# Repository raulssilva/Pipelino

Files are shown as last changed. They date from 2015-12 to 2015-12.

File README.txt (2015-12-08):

Esse projeto faz parte de um trabalho proposto pelo Professor:
	GUSTAVO GIRAO BARRETO DA SILVA
Aplicado na 3° Unidade do componente curricular:
	IMD0021 - ORGANIZAÇÃO E ARQUITETURA DE COMPUTADORES
	
Alunos: Felipe Barbalho Rocha, Raul Silveira Silva

Nome do projeto: Simulação em Arduino de um Pipeline com cinco estágios

Orientações:

Na pasta documentos contém o relatório e o esquemático usado para montagem 
dos circuitos com o Arduino. E na pasta Pipelino contém o código fonte usado 
em cada ardiuno no nosso projeto.

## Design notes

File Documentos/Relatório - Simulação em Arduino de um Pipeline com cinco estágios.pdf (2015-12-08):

UNIVERSIDADE FEDERAL DO RIO GRANDE DO NORTE INSTITUTO METRÓPOLE DIGITAL

Relatório

Nome do projeto: Simulação em Arduino de um Pipeline com cinco estágios

Alunos: Felipe Barbalho Rocha Raul Silveira Silva

Dezembro/2015

### 1. METODOLOGIA

A simulação consiste no uso de 4 Arduinos UNO conectados uns aos outros pela interface decomunicação Serial (pinos RX/TX) simulando 4 estágios de um Pipeline, o Instruction Fetch, Instruction Decoder, Executor e Data Memory. O 5º estágio (Write Back) foi simplificado para uma escrita no Arduino que guarda o banco de registradores. A simulação também possui 4 displays de LCD 16x2 para facilitar a visualização de qual instrução está sendo processada em cada estágio.
Para a parte de controle de saltos foi utilizado um 5º Arduino para simular o Controller que faz uma alteração no contador de programa para saltar para a próxima instrução. Nas próximas seções será exposto o funcionamento de cada Arduino/estágio, o conjunto de instruções que foram utilizadas e alguns aprimoramentos que podem ser pensados para uma próxima versão.
Para estabelecer uma comunicação padronizada e de fácil manipulação, foi definido um protocolo de 4 Bytes como mostra a Figura 1.

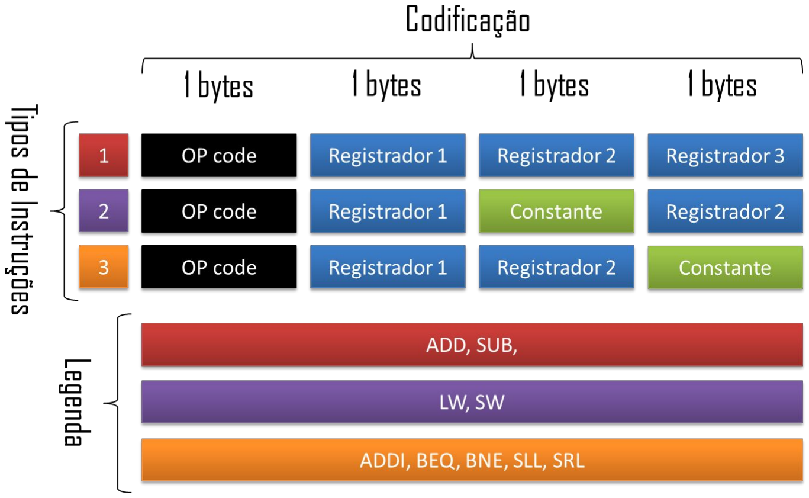
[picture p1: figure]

Figura 1 Codificação Utilizada para as instruções.

### 2. INSTRUCTION FETCH

Para a memória de instruções foi utilizado um Ethernet + SD shield para armazenar as instruções do programa a ser executado. Um arquivo com o nome “code.txt” armazenado na raíz de um cartão micro SD contem todo o código em Assembly MIPS do programa a ser executado. O Arduino lê esse arquivo atravéz do SD card reader do Ethernet Shield e envia cada instrução, separadamente com um delay de 3 segundos entre cada instrução, pela Serial (pino 1 TX) para o Instruction Decoder. O envio de cada OP code, cada identificador de registrador e constantes são baseadas em um protocolo descrito pela equipe de desenvolvimento, onde são enviados 4 Bytes por instrução.
As operações implementadas nessa simulação do Pipeline estão listadas abaixo com seu respectivo byte de identificação:
- ADD > 0b00000000.
- SUB > 0b00000001.
- ADDI > 0b00000010.
- LW | > 0b00000011.
- SW | > 0b00000100.
- SLL > 0b00000101.
- SRL > 0b00000110.
- BEQ > 0b00000111.
- BNE > 0b00001000.

Cada registrador também possui seu byte de identificação para facilitar na hora de transmitir cada instrução e de indentificálo no banco de registradores. Abaixo estão listados os registradores implementados nesse Pipeline e seu respectivo byte:

- $0 > 0b00000000.
- $s0 > 0b00000001.
- $s1 > 0b00000010.
- $s2 > 0b00000011.
- $s3 > 0b00000100.
- $s4 > 0b00000101.
- $s5 > 0b00000110.
- $s6 > 0b00000111.
- $s7 > 0b00001000.

As constantes necessárias em algumas operações possui um limite máximo de um byte, e são estritamente valores positivos, ou seja, podem variar de 0 à 255.
Caso ocorra alguma instrução de salto, uma flag é acionada com base na informação que foi recebida pela Serial (pino 0 RX) e salta a quantidade de linhas que o Controller informou.

### 3. INSTRUCTION DECODER

Na decodificação da instrução foi usada a EEPROM do Arduino para armazenar o banco de registradores. Como a EEPROM é um tipo de memória não volátil, é recomendado rodar um programa para zerar toda a EEPROM antes de iniciar o programa, caso contrário podemos encontrar valores de operações de outros programas.
Após feita a leitura dos registradores na EEPROM os mesmos são enviados pela Serial (pino 1 TX) para o Executor junto com o OP code, o byte do registrador a ser modificado e a constante, se necessário.
Em caso de salto, o Controller informa o estágio através da SoftwareSerial, que simula uma segunda porta de comunicação Serial, e o mesmo bloqueia a instrução lida pelo estágio anterior, depois da instrução de salto, e espera a próxima instrução a ser executada.
Quando houver um Write Back os dados do registrador e do valor também são recebidos pela Software Serial e é realizada a escrita na EEPROM, passando o byte do registrador a ser escrito e seu novo valor.

### 4. EXECUTOR

No 3º estágio do Pipeline são recebido pela Serial (pino 0 RX) o OP code, o registrador de escrita e os valores a serem operados, exceto no caso de instruções como LW e SW que são executadas no 4º estágio. Após identificadas e realizadas as operações temos dois casos de saida:

- Caso 1 Salto: A informação vai direta para o Controller que decide mudar a Flag de salto baseandose no que foi recebido. Tal informação é enviada através de uma SoftwareSerial do 3º estágio.
- Caso 2 Outras operações: Simplesmente são passadas adiante em 3 Bytes, um para o OP code, outro para o registrador de escrita e outro para o valor a ser escrito.

Para as operações de Load e Store, são enviados os 4 Bytes recebidos pelo 2º estágio.

### 5. DATA MEMORY

O 4° estágio é dedicado as instruções de escrita (Store Word SW) e leitura (Load Word LW) na memória. As demais instruções são simplesmente encaminhada para Write Back.
Nesta etapa utilizamos um array de bytes para simular a memória, com capacidade para 511 bytes, que corresponde ao valor de endereço máximo armazenado no registrador (255) somado com o valor máximo da constante de alinhamento da memória (255). Além disso um arquivo “MEM.txt” armazenado em um cartão SD é responsável por registrar as operações na memória e possibilita o acompanhamento dos dados que foram salvos na memória, como pode ser visualizado na Figura 2.

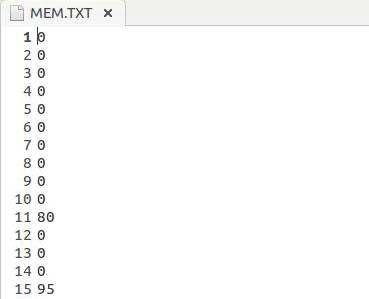
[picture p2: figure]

Figura 2 Arquivo de registro da memória.

### 6. CONTROLLER

Na simulação do Pipeline implementada o papel do Controller é identificar um instrução de salto e notificar o 1º e 2º estágio de uma necessidade de pular uma certa quantidade de linhas do programa. Essa notificação é feita ao mesmo tempo para ambos estágios usando uma comunicação Serial (pino 1 TX) comum aos dois primeiros Arduinos.

### 7. TRABALHOS FUTUROS

A atual implementação do Pipeline possui algumas limitações como não realizar o tratamento de bolhas (STALL) e os saltos somente podem ser feitos para frente, ou seja, programas com laços de repetições não podem ser descritos. Além disso como o clock não está sincronizado a primeira execução do programa pode não ser bem executada, para resolução de tal problema, fazse necessário que a alimentação dos Arduinos sejam feitas na seguinte ordem:

1. Controller.
2. Data Memory.
3. Executor.
4. Instruction Decoder.
5. Instruction Fetch.

Após essa ligação deve ser feito um reset em todos os Arduinos. Caso seja necessário aumentar o periodo do Clock, basta alterar a constante “CLOCK” em cada estágio do Pipeline.
Para uma segunda versão do simulador, a proposta é de implementar o tratamento de bolhas, melhorar o sincronismo do Clock e fazer modificações para que sejam executados programas com laços de repetição.

### 8. CONCLUSÃO

Foram implementadas na simulação do Pipeline algumas instruções Assembly MIPS e foi feito o tratamento de saltos. A Figura 3 representa o esquemático da simulação em Arduino e a Figura 4 representa o projeto já implementado usando os 5 Arduinos.

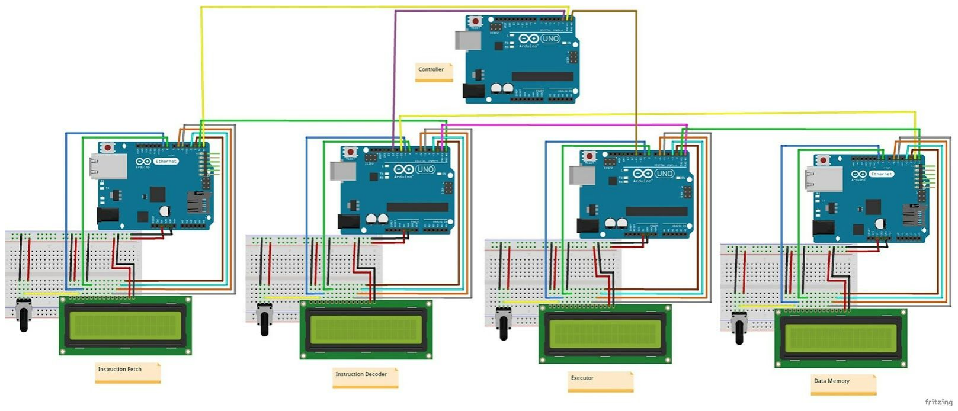
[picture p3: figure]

Figura 3 Esquemático.

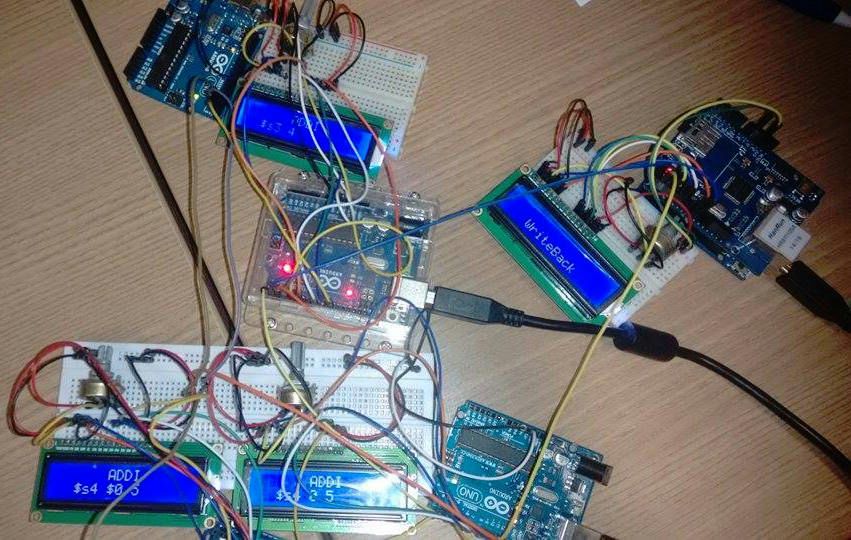
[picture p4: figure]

Figura 4 Simulação do Pipeline.

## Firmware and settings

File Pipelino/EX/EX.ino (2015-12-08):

/*
 Makers: Felipe Barbalho Rocha and Raul Silveira Silva
 
 The circuit (LCD 16x2):
 * LCD RS pin to digital pin 9
 * LCD Enable pin to digital pin 8
 * LCD D4 pin to digital pin 5
 * LCD D5 pin to digital pin 6
 * LCD D6 pin to digital pin 3
 * LCD D7 pin to digital pin 2
 * LCD R/W pin to ground
 * LCD VSS pin to ground
 * LCD VCC pin to 5V
 * 10K resistor:
 * ends to +5V and ground
 * wiper to LCD VO pin (pin 3)
 */

#include <LiquidCrystal.h>
#include <SoftwareSerial.h>

/**/
SoftwareSerial controllerSerial(10, 11); // RX, TX
LiquidCrystal lcd(9, 8, 5, 6, 3, 2);

/*Operadores para exibição no Display LCD apartir do código recebido pela serial*/
const String operators[] = {"ADD","SUB","ADDI","LW","SW","SLL","SRL","BEQ","BNE"};

/*Registradores para exibição no Dsiplay LCD apartir do código recebido pela serial*/
const String registers[] = {"$0","$s0","$s1","$s2","$s3","$s4","$s5","$s6","$s7"};

#define CLOCK 3000

void setup(){
  // Inicia o LCD 16x2
  lcd.begin(16, 2);
  // Inicia a Serial com um baudrate de 9600bps
  Serial.begin(9600);
  // Inicia a Serial do Write Back com um baudrate de 9600bps
  controllerSerial.begin(9600);
}

/*String que serão exibidas no LCD*/
String opCode = "";
String param1 = "";
String param2 = "";
String param3 = "";

/*intruções recebidas pela serial*/
byte opCodeByte = 0;
byte param1Byte = 0;
byte param2Byte = 0;
byte param3Byte = 0;

/*Irar auxiliar durante as operações*/
byte aux;


void loop(){
  
  if(Serial.available()){
    if(opCode == ""){
      /*Lêr o opcode*/	
      opCodeByte = (byte)(Serial.read()-48);

      /*Armazena a String do opcode para exibição no LCD*/	
      opCode = operators[opCodeByte];
    }
    
    switch(opCodeByte){
      case 0:
        /*Lêr da serial o valor dos parâmetros*/
        param1Byte = (byte)(Serial.read()-48);
        param2Byte = (byte)Serial.read();
        param3Byte = (byte)Serial.read();

 	      /*soma e armazena em param2Byte (por economia)*/
        param2Byte += param3Byte;
	
        /*Armazena nas String para exibição no LCD*/
        param1 = registers[param1Byte];
        param2 = (String)param2Byte;
	
        /*Envia os parâmetros para o estágio da Memória*/
        Serial.write(opCodeByte);
        Serial.write(param1Byte);
        Serial.write(param2Byte);

        break;
      case 1:
        /*Lêr da serial o valor dos parâmetros*/
        param1Byte = (byte)(Serial.read()-48);
        param2Byte = (byte)Serial.read();
        param3Byte = (byte)Serial.read();
	
        /*subtrai e armazena em param2Byte (por economia)*/
        param2Byte -= param3Byte;

        /*Armazena nas String para exibição no LCD*/
        param1 = registers[param1Byte];
        param2 = (String)param2Byte;

        /*Envia os parâmetros para o estágio da Memória*/
        Serial.write(opCodeByte);
        Serial.write(param1Byte);
        Serial.write(param2Byte); /*Não tratamos valores negativos*/

        break;
      case 2:
        /*Lêr da serial o valor dos parâmetros*/
        param1Byte = (byte)(Serial.read()-48);
        param2Byte = (byte)Serial.read();
        param3Byte = (byte)Serial.read();
	
        /*soma e armazena em param2Byte (por economia)*/
        param2Byte += param3Byte;

        /*Armazena nas String para exibição no LCD*/
        param1 = registers[param1Byte];
        param2 = (String)param2Byte;

        /*Envia os parâmetros para o estágio da Memória*/
        Serial.write(opCodeByte);
        Serial.write(param1Byte);
        Serial.write(param2Byte);

        break;
      case 3:
        /*Lêr da serial o valor dos parâmetros*/
        param1Byte = (byte)(Serial.read()-48);
        param2Byte = (byte)Serial.read();
        param3Byte = (byte)Serial.read();

        /*Armazena nas String para exibição no LCD*/
        param1 = registers[param1Byte];
        param2 = (String)param2Byte;
        param3 = (String)param3Byte;
        
        /*Envia os parâmetros para o estágio da Memória*/
        Serial.write(opCodeByte);
        Serial.write(param1Byte);
        Serial.write(param2Byte);
        Serial.write(param3Byte);

        break;
      case 4:
        /*Lêr da serial o valor dos parâmetros*/
        param1Byte = (byte)Serial.read();
        param2Byte = (byte)Serial.read();
        param3Byte = (byte)Serial.read();

        /*Armazena nas String para exibição no LCD*/
        param1 = (String)param1Byte;
        param2 = (String)param2Byte;
        param3 = (String)param3Byte;

        /*Envia os parâmetros para o estágio da Memória*/
        Serial.write(opCodeByte);
        Serial.write(param1Byte);
        Serial.write(param2Byte);
        Serial.write(param3Byte);

        break;
      case 5:
        /*Lêr da serial o valor dos parâmetros*/
        param1Byte = (byte)(Serial.read()-48);
        param2Byte = (byte)Serial.read();
        param3Byte = (byte)Serial.read();

        /*Variavel para alocar o valor com o shift*/
        aux = (param2Byte << param3Byte);

        /*Armazena nas String para exibição no LCD*/
        param1 = registers[param1Byte];
        param2 = (String)aux;

        /*Envia os parâmetros para o estágio da Memória*/
        Serial.write(opCodeByte);
        Serial.write(param1Byte);
        Serial.write(aux);

        break;
      case 6:
        /*Lêr da serial o valor dos parâmetros*/
        param1Byte = (byte)(Serial.read()-48);
        param2Byte = (byte)Serial.read();
        param3Byte = (byte)Serial.read();

        /*Variavel para alocar o valor com o shift*/
        aux = (param2Byte >> param3Byte);

        /*Armazena nas String para exibição no LCD*/
        param1 = registers[param1Byte];
        param2 = (String)aux;

        /*Envia os parâmetros para o estágio da Memória*/
        Serial.write(opCodeByte);
        Serial.write(param1Byte);
        Serial.write(aux);

        break;

      case 7:
        /*Lêr da serial o valor dos parâmetros*/
        param1Byte = (byte)Serial.read();
        param2Byte = (byte)Serial.read();

        /*Verificacao booleana do brench*/
        param1 = "False";
        if(param1Byte == param2Byte){
          aux = 1;
          param1 = "True";
          param2Byte = (byte)Serial.read();
          param2 = (String)param2Byte;
          controllerSerial.print(param2Byte);
        }

        break;

      default:
        /*Lêr da serial o valor dos parâmetros*/
        param1Byte = (byte)Serial.read();
        param2Byte = (byte)Serial.read();
	
        /*Verificacao booleana do brench*/
        param1 = "False";
        if(param1Byte != param2Byte){
          aux = 1;
          param1 = "True";
          param2Byte = (byte)Serial.read();
          param2 = (String)param2Byte;
          controllerSerial.print(param2Byte);
        }
    }
    /*Exibe no LCD a operacao e os valores operados*/
    lcd.clear();
    lcd.setCursor(6,0);
    lcd.print(opCode);
    lcd.setCursor(2,1);
    lcd.print(param1 + " " + param2 + " " + param3);
  }
  /*Limpa as variaveis de entrada*/
  opCode = "";
  param1 = "";
  param2 = "";
  param3 = "";
 
  delay(CLOCK);
  lcd.clear();
}

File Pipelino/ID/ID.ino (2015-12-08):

/*
 Makers: Felipe Barbalho Rocha and Raul Silveira Silva
 
 The circuit (LCD 16x2):
 * LCD RS pin to digital pin 9
 * LCD Enable pin to digital pin 8
 * LCD D4 pin to digital pin 5
 * LCD D5 pin to digital pin 6
 * LCD D6 pin to digital pin 3
 * LCD D7 pin to digital pin 2
 * LCD R/W pin to ground
 * LCD VSS pin to ground
 * LCD VCC pin to 5V
 * 10K resistor:
 * ends to +5V and ground
 * wiper to LCD VO pin (pin 3)
 */

#include <EEPROM.h> 
#include <LiquidCrystal.h>
#include <SoftwareSerial.h>

#define CLOCK 3000

// Definicao dos pinos do LCD para exibicao das informacoes
LiquidCrystal lcd(9, 8, 5, 6, 3, 2);
// Definicao de uma segunda porta de comunicacao Serial para o Write Back
SoftwareSerial controllerSerial(10, 11); // RX, TX

// Array com as operacoes que podem ser usadas. Cada indice representa o OP code
const String operators[] = {"ADD","SUB","ADDI","LW","SW","SLL","SRL","BEQ","BNE"};
// Array com os registradores que podem ser usados. Cada indice representa a referencia do registrador na EEPROM
const String registers[] = {"$0","$s0","$s1","$s2","$s3","$s4","$s5","$s6","$s7"};

void setup(){
  // Inicia o LCD 16x2
  lcd.begin(16, 2);
  // Inicia a Serial com um baudrate de 9600bps
  Serial.begin(9600);
  // Inicia a Serial do Write Back com um baudrate de 9600bps
  controllerSerial.begin(9600);
  // Pino de notificacao de salto
  pinMode(12, INPUT);
}

// Variaveis de exibicao no LCD
String opCode = "";
String param1 = "";
String param2 = "";
String param3 = "";

// Variaveis de indentificadores de OP code, registradores e constantes
byte opCodeByte = 0;
byte param1Byte = 0;
byte param2Byte = 0;
byte param3Byte = 0;

// Flag para tratamento de salto
bool brenchFlag = false;

void loop(){
  // Verifica se houve salto e ativa a flag
  if(digitalRead(12)==1){
    controllerSerial.read();
    brenchFlag = true;
  // Verifica se houve Write Back e escreva na EEPROM
  }else if(controllerSerial.available()){
    byte address = controllerSerial.read();
    byte value = controllerSerial.read();
    writeRegister(address, value);
  }
  // Verifica se uma nova instrucao chegou pela Serial
  if(Serial.available()){
    // Se o OP code nao tiver sido lido, significa que o primeiro byte e do OP code
    if(opCode == ""){
      opCodeByte = (byte)(Serial.read()-48);
      opCode = operators[opCodeByte];
      // Se a Flag nao estiver ativada, a proxima instrucao deve ser executada
      if(!brenchFlag){
        Serial.print(opCodeByte);
      }
    }
    
    // Apos a leitura do OP code e verificado quais dados devem ser lidos, baseados no OP code
    switch(opCodeByte){
      case 0:
        // ADD
        param1Byte = (byte)(Serial.read()-48);
        param1 = registers[param1Byte];
        param2Byte = (byte)(Serial.read()-48);
        param2 = (String)readRegister(param2Byte);
        param3Byte = (byte)(Serial.read()-48);
        param3 = (String)readRegister(param3Byte);
        // Se a Flag nao estiver ativada, a proxima instrucao deve ser executada
        if(!brenchFlag){
          Serial.print(param1Byte);
          Serial.print((char)(param2.toInt()));
          Serial.print((char)(param3.toInt()));
        }
        break;
      case 1:
        // SUB
        param1Byte = (byte)(Serial.read()-48);
        param1 = registers[param1Byte];
        param2Byte = (byte)(Serial.read()-48);
        param2 = (String)readRegister(param2Byte);
        param3Byte = (byte)(Serial.read()-48);
        param3 = (String)readRegister(param3Byte);
        // Se a Flag nao estiver ativada, a proxima instrucao deve ser executada
        if(!brenchFlag){
          Serial.print(param1Byte);
          Serial.print((char)(param2.toInt()));
          Serial.print((char)(param3.toInt()));
        }
        break;
      case 2:
        // ADDI
        param1Byte = (byte)(Serial.read()-48);
        param1 = registers[param1Byte];
        param2Byte = (byte)(Serial.read()-48);
        param2 = (String)readRegister(param2Byte);
        param3Byte = (byte)(Serial.read()-48);
        param3 = (String)param3Byte;
        // Se a Flag nao estiver ativada, a proxima instrucao deve ser executada
        if(!brenchFlag){
          Serial.print(param1Byte);
          Serial.print((char)(param2.toInt()));
          Serial.print((char)param3Byte);
        }
        break;
      case 3:
        //LW
        param1Byte = (byte)(Serial.read()-48);
        param1 = registers[param1Byte];
        param2Byte = (byte)Serial.read();
        param2 = (String)param2Byte;
        param3Byte = (byte)(Serial.read()-48);
        param3 = (String)readRegister(param3Byte);
        // Se a Flag nao estiver ativada, a proxima instrucao deve ser executada
        if(!brenchFlag){
          Serial.print(param1Byte);
          Serial.print((char)param2Byte);
          Serial.print((char)(param3.toInt()));
        }
        break;
      case 4:
        // SW
        param1Byte = (byte)(Serial.read()-48);
        param1 = (String)readRegister(param1Byte);
        param2Byte = (byte)Serial.read();
        param2 = (String)param2Byte;
        param3Byte = (byte)(Serial.read()-48);
        param3 = (String)readRegister(param3Byte);
        // Se a Flag nao estiver ativada, a proxima instrucao deve ser executada
        if(!brenchFlag){
          Serial.print((char)(param1.toInt()));
          Serial.print((char)param2Byte);
          Serial.print((char)(param3.toInt()));
        }
        break;
      case 5:
        // SLL
        param1Byte = (byte)(Serial.read()-48);
        param1 = registers[param1Byte];
        param2Byte = (byte)(Serial.read()-48);
        param2 = (String)readRegister(param2Byte);
        param3Byte = (byte)(Serial.read()-48);
        param3 = (String)param3Byte;
        // Se a Flag nao estiver ativada, a proxima instrucao deve ser executada
        if(!brenchFlag){
          Serial.print(param1Byte);
          Serial.print((char)(param2.toInt()));
          Serial.print((char)param3Byte);
        }
        break;
      case 6:
        // SRL
        param1Byte = (byte)(Serial.read()-48);
        param1 = registers[param1Byte];
        param2Byte = (byte)(Serial.read()-48);
        param2 = (String)readRegister(param2Byte);
        param3Byte = (byte)(Serial.read()-48);
        param3 = (String)param3Byte;
        // Se a Flag nao estiver ativada, a proxima instrucao deve ser executada
        if(!brenchFlag){
          Serial.print(param1Byte);
          Serial.print((char)(param2.toInt()));
          Serial.print((char)param3Byte);
        }
        break;
      case 7:
        // BEQ
        param1Byte = (byte)(Serial.read()-48);
        param1 = (String)readRegister(param1Byte);
        param2Byte = (byte)(Serial.read()-48);
        param2 = (String)readRegister(param2Byte);
        param3Byte = (byte)(Serial.read()-48);
        param3 = (String)param3Byte;
        // Se a Flag nao estiver ativada, a proxima instrucao deve ser executada
        if(!brenchFlag){
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

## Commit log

2015-11-25 adicionei uns arquivos de testes
2015-11-28 Organização de testes
2015-11-28 Mudei o pino do RS de 10 para 9, tava em conflito com o writeBack
2015-11-28 Implementação do 1º estágio (sem controle de bolha e salto)
2015-11-30 Inicio de implementação da MEM
2015-12-01 Implementação parcial do controler e implementação do tratamento de brench (a constante idica quantas linhas serão puladas)
2015-12-08 Documentação concluída
    [pipeline.fzz]
2015-12-08 Implementação do esquemático
    [pipeline.fzz]
2015-12-08 Apaguei o que era desnecessárioe fiz modificações no esquemático
    [Pipeline - Esquematização.fzz, pipeline.fzz]
